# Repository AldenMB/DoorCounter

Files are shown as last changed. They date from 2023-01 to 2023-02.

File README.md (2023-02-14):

# DoorCounter
A IR beam detector for counting when people enter or exit a room, running on a Raspberry Pi Pico.

The DS1302 driver is from [Omar Benhamid](https://github.com/omarbenhamid/micropython-ds1302-rtc). Thanks Omar!

The rotary encoder driver is from [Mike Teachman](https://github.com/miketeachman/micropython-rotary). Thanks Mike!

The circuit board will be held in using 5/16 inch 2-28 pan-head screws. The heads have a diameter of 5/32 inches = 4 mm, The threaded portion has an exterior diameter of 3/32in = 2.3mm, and an inner diameter of about 1/16in = 1.6mm. They measure 3/8 inch in length, counting the head.

## Prototype error
Caution: in my first batch of boards I made an error in the schematic. Of course I take full responsibility, but I feel some blame shoudl also be shared by whoever decided to give one pin of the SD card the designation `DI` and another one the designation `D1`.

The error has already been fixed on the schematic, and it's easy enough to fix. Just break the trace going from `GP3` to the SD card, and instead run a wire to one side of `R3`. Like this:
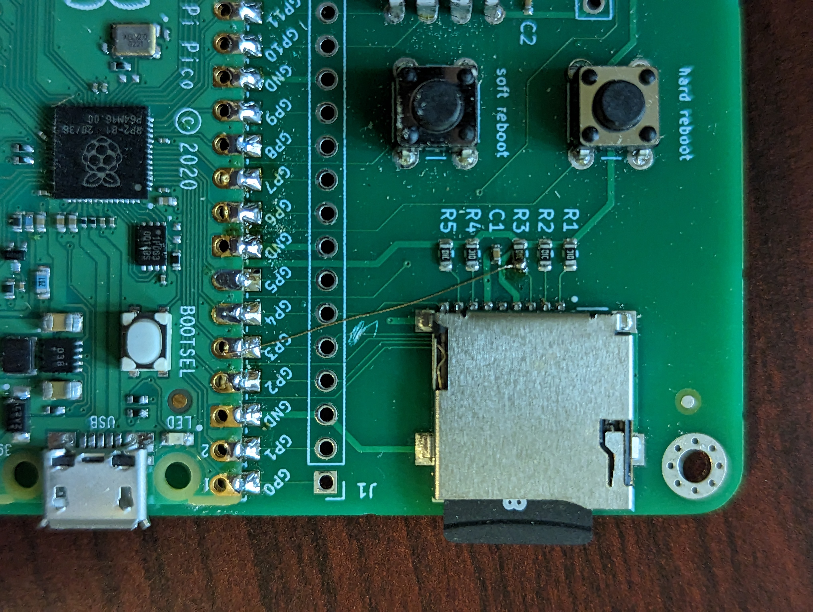
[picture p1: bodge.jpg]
a picture of the board, repaired as described above.

Of course, if you don't use the SD card then this makes no difference. It is still pulled up to the `3V3` line with a 10k resistor.

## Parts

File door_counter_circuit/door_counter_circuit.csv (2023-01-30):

Comment | Designator | Footprint | LCSC
0.1uF | C1,C2,C3,C4,C5,C6,C7 | Capacitor_SMD:C_0402_1005Metric | C1525
TF-01A | MICRO_SD1 | tf01a:TF-01A | C91145
MMS9013-H-TP | Q1 | Package_TO_SOT_SMD:SOT-23 | C90160
10k | R1,R2,R3,R4,R5,R6 | Resistor_SMD:R_0603_1608Metric | C25804
220 | R7 | Resistor_SMD:R_0805_2012Metric | C17557

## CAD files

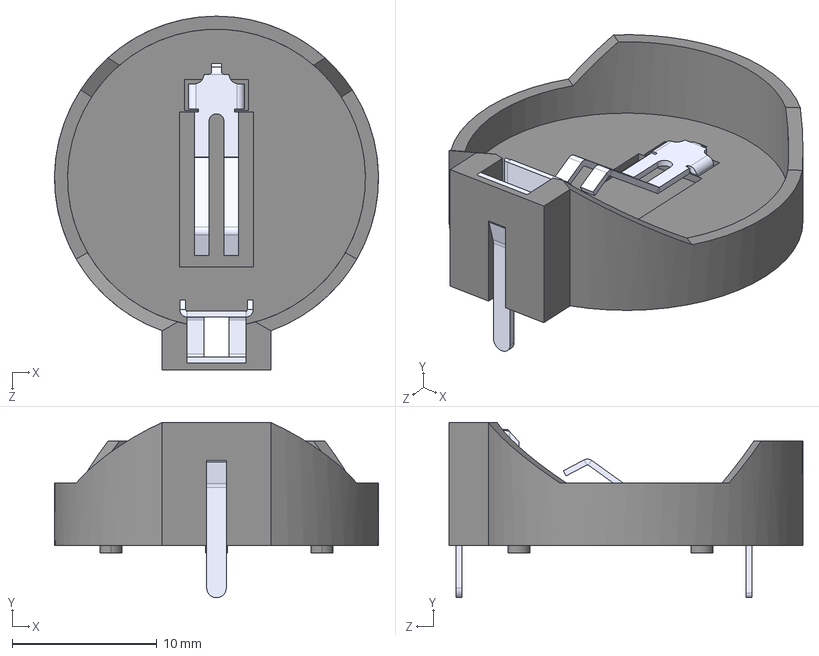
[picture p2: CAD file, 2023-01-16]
door_counter_circuit/BS-7/BS-7.step
22.3 x 12.1 x 24.4 mm

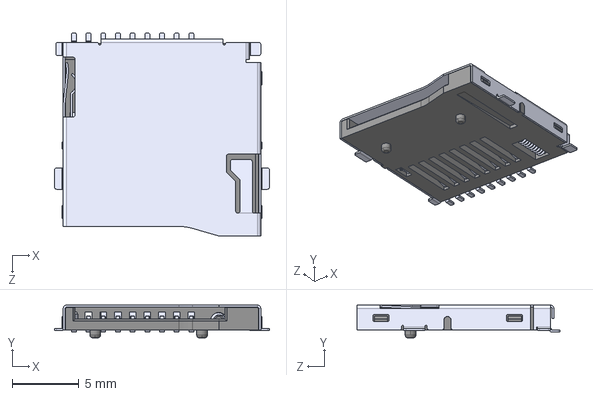
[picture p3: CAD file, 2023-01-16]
door_counter_circuit/TF-01A/TF-01A.step
16.1 x 2.45 x 15.2 mm

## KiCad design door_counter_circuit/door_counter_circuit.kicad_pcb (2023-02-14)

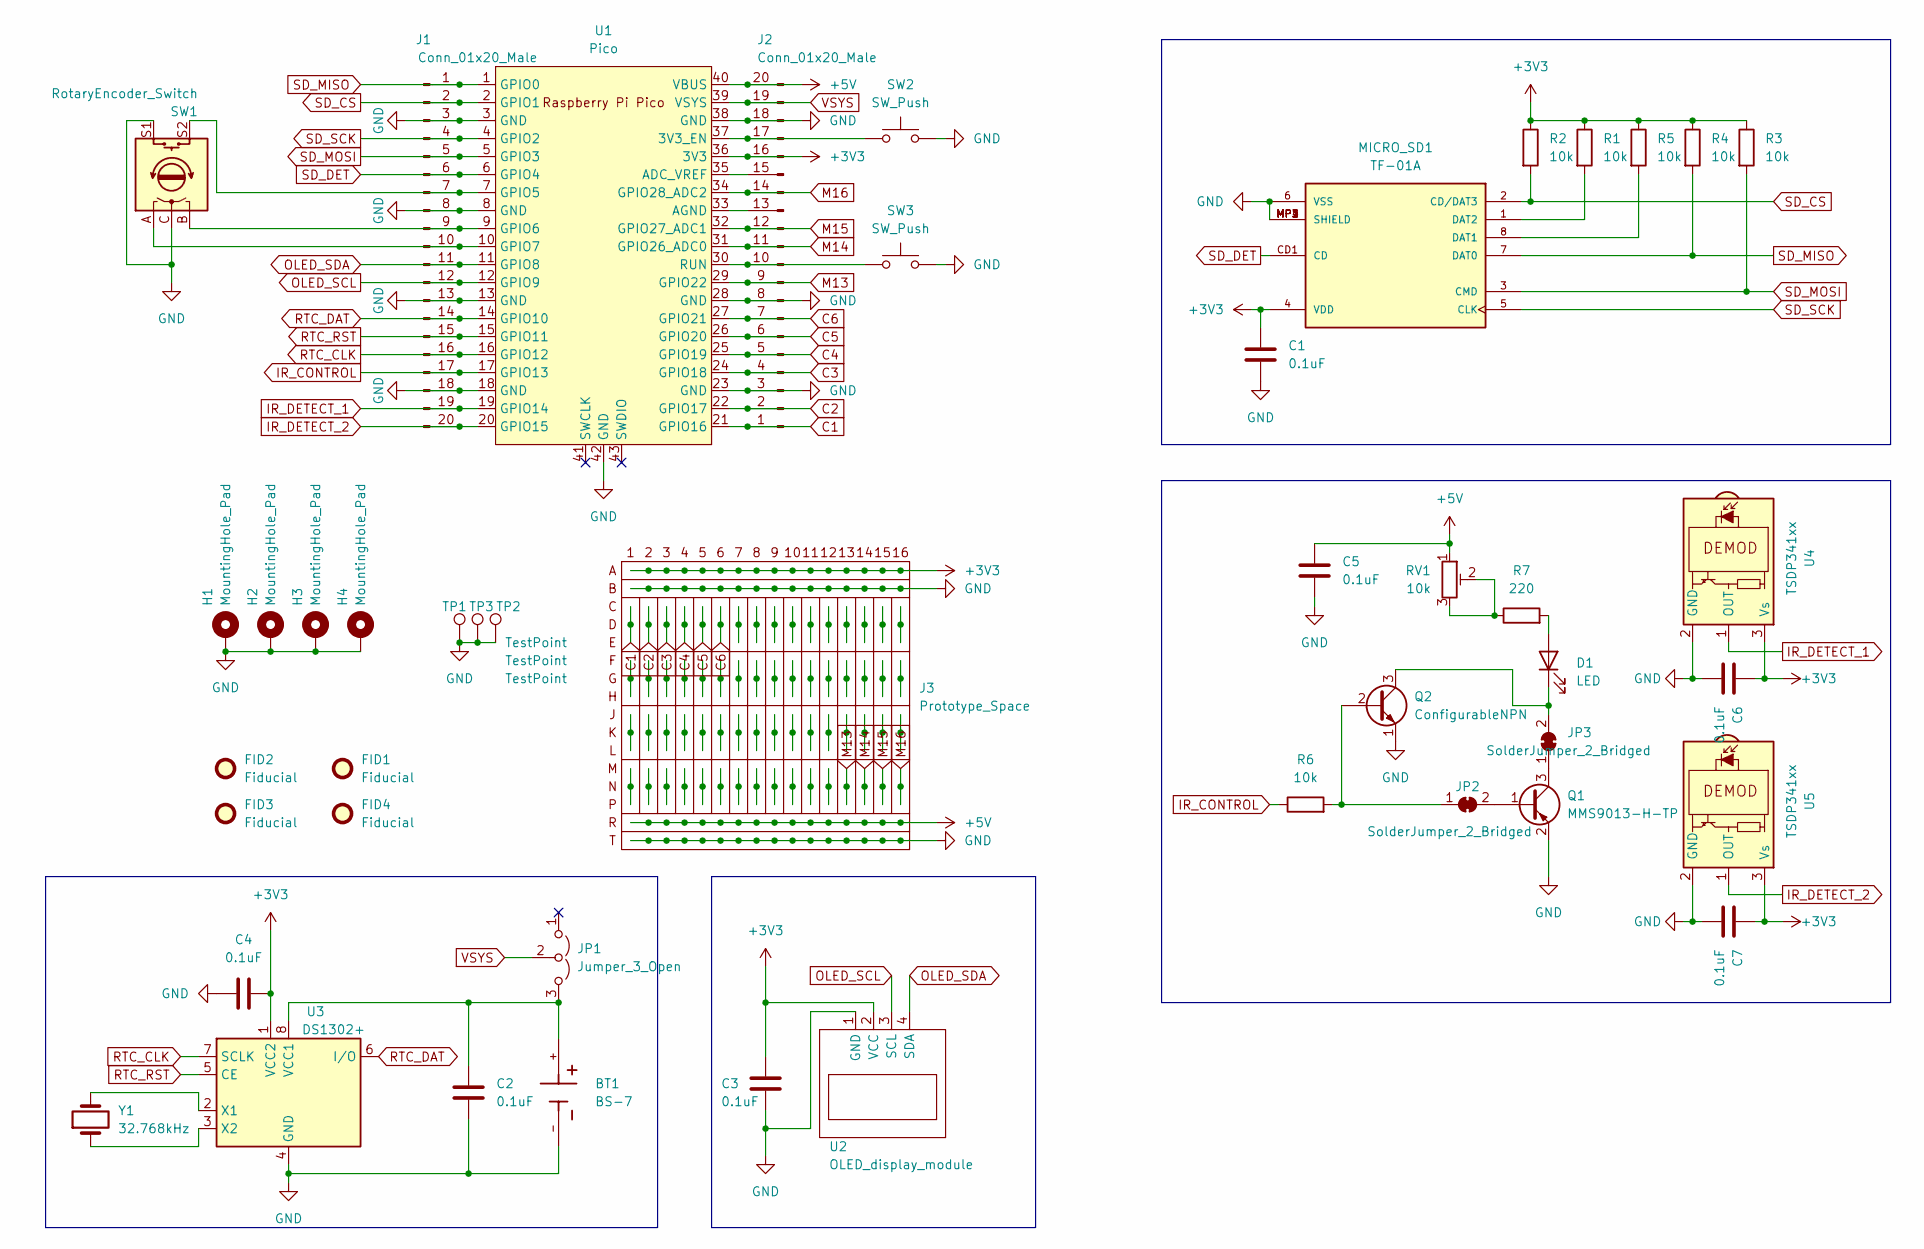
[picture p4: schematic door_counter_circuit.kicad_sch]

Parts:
BT1: BS-7; BAT_BS-7; PARTREV H
C1, C2, C3, C4, C5, C6, C7: 0.1uF; C_0402_1005Metric; LCSC C1525
D1: LED; LED_D3.0mm_Horizontal_O1.27mm_Z6.0mm
FID1, FID2, FID3, FID4: Fiducial; Fiducial_1mm_Mask2mm
H1, H2, H3, H4: MountingHole_Pad; MountingHole_2.5mm_Pad_Via
J1, J2: Conn_01x20_Male; PinHeader_1x20_P2.54mm_Vertical
J3: Prototype_Space; Prototype Space
JP1: Jumper_3_Open; PinHeader_1x03_P2.54mm_Vertical
JP2, JP3: SolderJumper_2_Bridged; SolderJumper-2_P1.3mm_Bridged_RoundedPad1.0x1.5mm
MICRO_SD1: TF-01A; LCSC C91145
Q1: MMS9013-H-TP; SOT-23; LCSC C90160
Q2: ConfigurableNPN; TO-92-configurable
R1, R2, R3, R4, R5, R6: 10k; R_0603_1608Metric; LCSC C25804
R7: 220; R_0805_2012Metric; LCSC C17557
RV1: 10k; Potentiometer_Bourns_3296W_Vertical
SW1: RotaryEncoder_Switch; RotaryEncoder_Alps_EC11E-Switch_Vertical_H20mm
SW2, SW3: SW_Push; SW_PUSH_6mm_H4.3mm
TP1, TP2, TP3: TestPoint; TestPoint_Pad_4.0x4.0mm
U1: Pico; RPi_Pico_SMD_TH
U2: OLED_display_module; SSD1306
U3: DS1302+; DIP-8_W7.62mm
U4, U5: TSDP341xx; Vishay_MOLD-3Pin
Y1: 32.768kHz; Crystal_C26-LF_D2.1mm_L6.5mm_Horizontal

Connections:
+3V3: C1.1, C3.1, C4.2, C6.1, C7.1, J2.16, J3.1A, J3.2A, J3.3A, J3.4A, J3.5A, J3.6A, J3.7A, J3.8A, J3.9A, J3.10A, J3.11A, J3.12A, J3.13A, J3.14A, J3.15A, J3.16A, MICRO_SD1.4 (VDD), R1.1, R2.1, R3.1, R4.1, R5.1, U1.36 (3V3), U2.2 (VCC), U3.1 (VCC2), U4.3 (Vs), U5.3 (Vs)
+5V: C5.1, J2.20, J3.1R, J3.2R, J3.3R, J3.4R, J3.5R, J3.6R, J3.7R, J3.8R, J3.9R, J3.10R, J3.11R, J3.12R, J3.13R, J3.14R, J3.15R, J3.16R, RV1.1, U1.40 (VBUS)
C1: J2.1, J3.1C, J3.1D, J3.1E, U1.21 (GPIO16)
C2: J2.2, J3.2C, J3.2D, J3.2E, U1.22 (GPIO17)
C3: J2.4, J3.3C, J3.3D, J3.3E, U1.24 (GPIO18)
C4: J2.5, J3.4C, J3.4D, J3.4E, U1.25 (GPIO19)
C5: J2.6, J3.5C, J3.5D, J3.5E, U1.26 (GPIO20)
C6: J2.7, J3.6C, J3.6D, J3.6E, U1.27 (GPIO21)
GND: BT1.-, C1.2, C2.2, C3.2, C4.1, C5.2, C6.2, C7.2, H1.1, H2.1, H3.1, H4.1, J1.3, J1.8, J1.13, J1.18, J2.3, J2.8, J2.18, J3.1B, J3.1T, J3.2B, J3.2T, J3.3B, J3.3T, J3.4B, J3.4T, J3.5B, J3.5T, J3.6B, J3.6T, J3.7B, J3.7T, J3.8B, J3.8T, J3.9B, J3.9T, J3.10B, J3.10T, J3.11B, J3.11T, J3.12B, J3.12T, J3.13B, J3.13T, J3.14B, J3.14T, J3.15B, J3.15T, J3.16B, J3.16T, MICRO_SD1.6 (VSS), MICRO_SD1.MP1 (SHIELD), MICRO_SD1.MP2 (SHIELD), MICRO_SD1.MP3 (SHIELD), MICRO_SD1.MP4 (SHIELD), Q1.2 (E), Q2.1 (E), Q2.4 (emitter_duplicate), SW1.C, SW1.S1, SW2.2, SW3.2, TP1.1, TP2.1, TP3.1, U1.3 (GND), U1.8 (GND), U1.13 (GND), U1.18 (GND), U1.23 (GND), U1.28 (GND), U1.38 (GND), U1.42 (GND), U2.1 (GND), U3.4 (GND), U4.2 (GND), U5.2 (GND)
IR_CONTROL: J1.17, R6.1, U1.17 (GPIO13)
IR_DETECT_1: J1.19, U1.19 (GPIO14), U4.1 (OUT)
IR_DETECT_2: J1.20, U1.20 (GPIO15), U5.1 (OUT)
M13: J2.9, J3.13M, J3.13N, J3.13P, U1.29 (GPIO22)
M14: J2.11, J3.14M, J3.14N, J3.14P, U1.31 (GPIO26_ADC0)
M15: J2.12, J3.15M, J3.15N, J3.15P, U1.32 (GPIO27_ADC1)
M16: J2.14, J3.16M, J3.16N, J3.16P, U1.34 (GPIO28_ADC2)
unnamed: BT1.+, C2.1, JP1.3 (B), U3.8 (VCC1)
unnamed: D1.1 (K), JP3.2 (B), Q2.3 (C), Q2.5 (collector_duplicate)
unnamed: D1.2 (A), R7.2
unnamed: J1.7, SW1.S2, U1.7 (GPIO5)
unnamed: J1.9, SW1.B, U1.9 (GPIO6)
unnamed: J1.10, SW1.A, U1.10 (GPIO7)
unnamed: J2.10, SW3.1, U1.30 (RUN)
unnamed: J2.13, U1.33 (AGND)
unnamed: J2.15, U1.35 (ADC_VREF)
unnamed: J2.17, SW2.1, U1.37 (3V3_EN)
unnamed: J3.1F, J3.1G, J3.1H
unnamed: J3.1J, J3.1K, J3.1L
unnamed: J3.1M, J3.1N, J3.1P
unnamed: J3.2F, J3.2G, J3.2H
unnamed: J3.2J, J3.2K, J3.2L
unnamed: J3.2M, J3.2N, J3.2P
unnamed: J3.3F, J3.3G, J3.3H
unnamed: J3.3J, J3.3K, J3.3L
unnamed: J3.3M, J3.3N, J3.3P
unnamed: J3.4F, J3.4G, J3.4H
unnamed: J3.4J, J3.4K, J3.4L
unnamed: J3.4M, J3.4N, J3.4P
unnamed: J3.5F, J3.5G, J3.5H
unnamed: J3.5J, J3.5K, J3.5L
unnamed: J3.5M, J3.5N, J3.5P
unnamed: J3.6F, J3.6G, J3.6H
unnamed: J3.6J, J3.6K, J3.6L
unnamed: J3.6M, J3.6N, J3.6P
unnamed: J3.7C, J3.7D, J3.7E
unnamed: J3.7F, J3.7G, J3.7H
unnamed: J3.7J, J3.7K, J3.7L
unnamed: J3.7M, J3.7N, J3.7P
unnamed: J3.8C, J3.8D, J3.8E
unnamed: J3.8F, J3.8G, J3.8H
unnamed: J3.8J, J3.8K, J3.8L
unnamed: J3.8M, J3.8N, J3.8P
unnamed: J3.9C, J3.9D, J3.9E
unnamed: J3.9F, J3.9G, J3.9H
unnamed: J3.9J, J3.9K, J3.9L
unnamed: J3.9M, J3.9N, J3.9P
unnamed: J3.10C, J3.10D, J3.10E
unnamed: J3.10F, J3.10G, J3.10H
unnamed: J3.10J, J3.10K, J3.10L
unnamed: J3.10M, J3.10N, J3.10P
unnamed: J3.11C, J3.11D, J3.11E
unnamed: J3.11F, J3.11G, J3.11H
unnamed: J3.11J, J3.11K, J3.11L
unnamed: J3.11M, J3.11N, J3.11P
unnamed: J3.12C, J3.12D, J3.12E
unnamed: J3.12F, J3.12G, J3.12H
unnamed: J3.12J, J3.12K, J3.12L
unnamed: J3.12M, J3.12N, J3.12P
unnamed: J3.13C, J3.13D, J3.13E
unnamed: J3.13F, J3.13G, J3.13H
unnamed: J3.13J, J3.13K, J3.13L
unnamed: J3.14C, J3.14D, J3.14E
unnamed: J3.14F, J3.14G, J3.14H
unnamed: J3.14J, J3.14K, J3.14L
unnamed: J3.15C, J3.15D, J3.15E
unnamed: J3.15F, J3.15G, J3.15H
unnamed: J3.15J, J3.15K, J3.15L
unnamed: J3.16C, J3.16D, J3.16E
unnamed: J3.16F, J3.16G, J3.16H
unnamed: J3.16J, J3.16K, J3.16L
unnamed: JP2.1 (A), Q2.2 (B), R6.2
unnamed: JP2.2 (B), Q1.1 (B)
unnamed: JP3.1 (A), Q1.3 (C)
unnamed: MICRO_SD1.1 (DAT2), R1.2
unnamed: MICRO_SD1.8 (DAT1), R5.2
unnamed: R7.1, RV1.2, RV1.3
unnamed: U3.2 (X1), Y1.2
unnamed: U3.3 (X2), Y1.1
OLED_SCL: J1.12, U1.12 (GPIO9), U2.3 (SCL)
OLED_SDA: J1.11, U1.11 (GPIO8), U2.4 (SDA)
RTC_CLK: J1.16, U1.16 (GPIO12), U3.7 (SCLK)
RTC_DAT: J1.14, U1.14 (GPIO10), U3.6 (I/O)
RTC_RST: J1.15, U1.15 (GPIO11), U3.5 (CE)
SD_CS: J1.2, MICRO_SD1.2 (CD/DAT3), R2.2, U1.2 (GPIO1)
SD_DET: J1.6, MICRO_SD1.CD1 (CD), U1.6 (GPIO4)
SD_MISO: J1.1, MICRO_SD1.7 (DAT0), R4.2, U1.1 (GPIO0)
SD_MOSI: J1.5, MICRO_SD1.3 (CMD), R3.2, U1.5 (GPIO3)
SD_SCK: J1.4, MICRO_SD1.5 (CLK), U1.4 (GPIO2)
VSYS: J2.19, JP1.2 (C), U1.39 (VSYS)

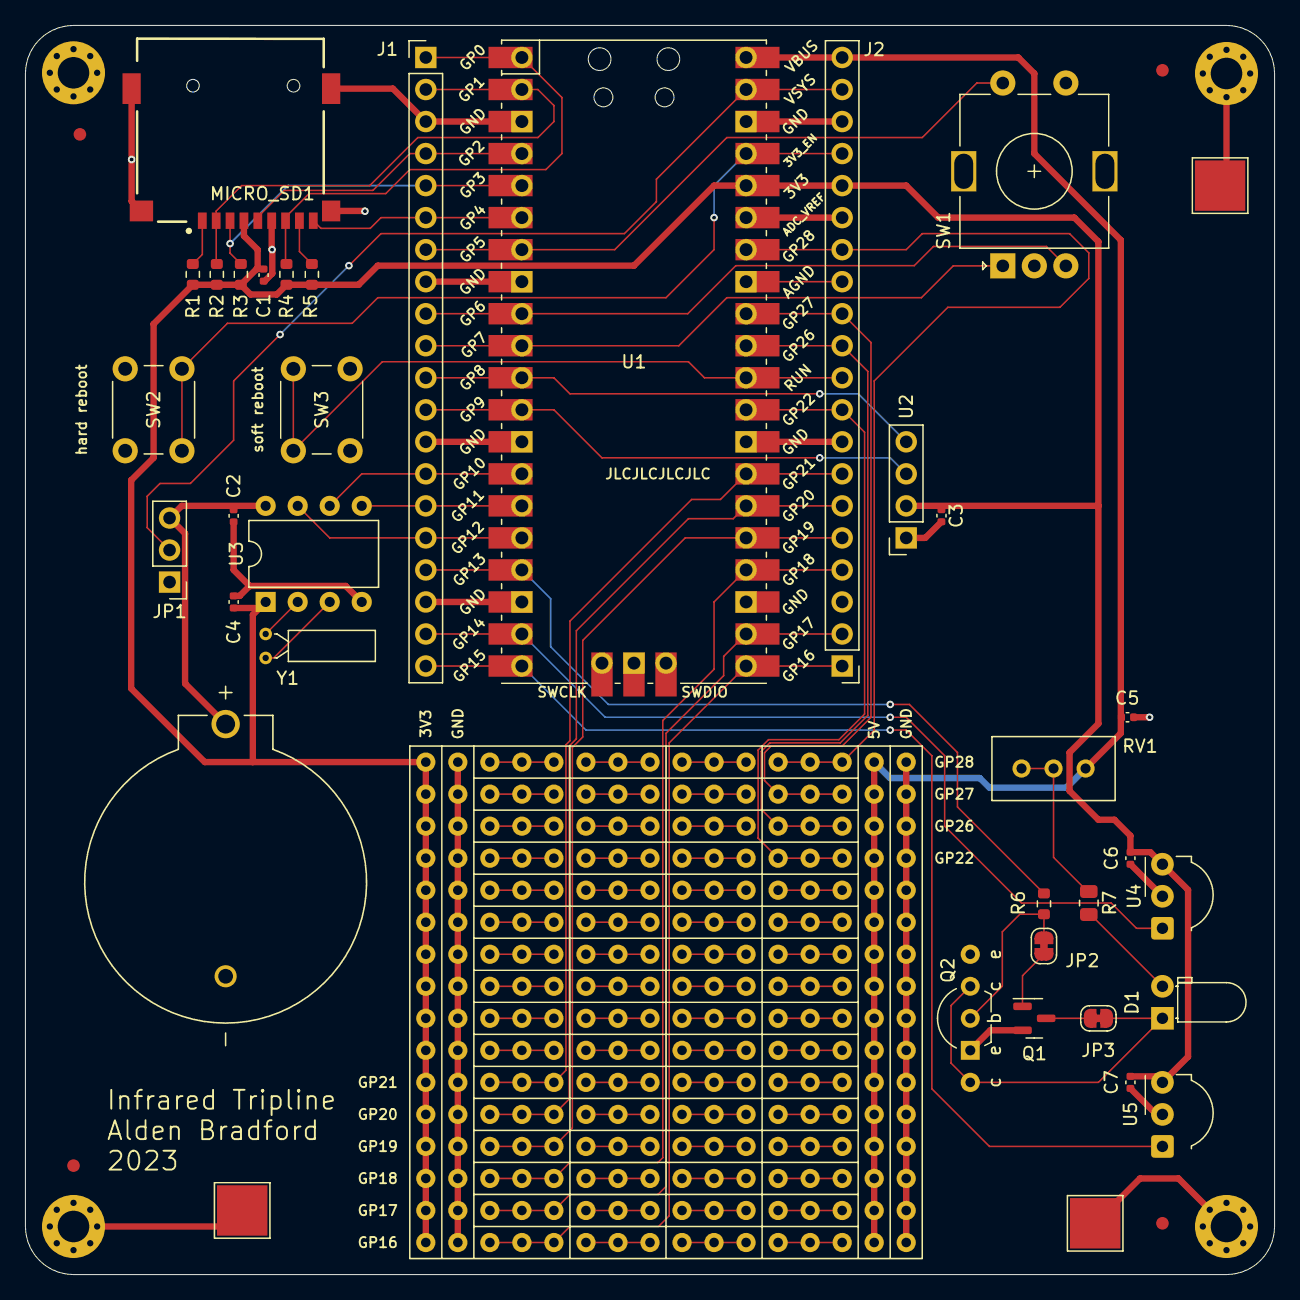
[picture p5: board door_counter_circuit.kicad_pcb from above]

Board: 4 copper layers, 99.1 x 99.1 mm, 46 parts (0 on the bottom side), 99 nets.

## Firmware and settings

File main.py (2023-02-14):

from machine import Pin, I2C, RTC
import time
import rp2
import ssd1306
import rtc_sync
from rotary_irq_rp2 import RotaryIRQ

rtc_sync.load()
clock = RTC()

samples_per_reading = 4
mask = int('0b'+'10'*samples_per_reading)

@rp2.asm_pio(sideset_init=rp2.PIO.OUT_LOW, autopush=True, fifo_join = rp2.PIO.JOIN_RX, push_thresh=samples_per_reading*2)
def ir_echo():
    # datasheet specifies relaxation time >= 5ms
    # total instructions: 3 + 4(2 + 32*8) = 1035
    # 1035 instructions / 76k instr/sec = 13.6 ms
    set(y, 4)  # 1
    label("blank")
    set(x, 31)  # 4 * 1
    label("blank_inner")
    jmp(x_dec, "blank_inner").delay(7)  # 4*32*8
    jmp(y_dec, "blank")  # 4 * 1

    # datasheet specifies at least 10 pulses per burst
    # NEC protocol uses 21 pulse and 237 pulse bursts
    set(x, 20)  # 1
    label("burst")
    nop().side(1)
    jmp(x_dec, "burst").side(0)
    # 32 pulses / 38khz = 842 us
    
    # response may terminate as early as 6 instructions after last pulse
    # we should take the measurement immediately
    in_(pins, 2) # 1

# asm_pio does not have an input pullup flag, for some reason. Oh well. Set them manually.
Pin(14, Pin.IN, Pin.PULL_UP)
Pin(15, Pin.IN, Pin.PULL_UP)
sensor = rp2.StateMachine(0, ir_echo, freq=2 * 38_000, sideset_base=Pin(13), in_base = Pin(14))
sensor.active(True)

i2c = I2C(id=0, sda=Pin(8), scl=Pin(9))
display = ssd1306.SSD1306_I2C(128, 64, i2c)
display.text('Hello, World!', 0, 0, 1)
display.show()

onboard_led = Pin(25, Pin.OUT)

rotary = RotaryIRQ(6, 7, pull_up=True)
button = Pin(3, Pin.IN, Pin.PULL_UP)

while True:
    display.fill(0)
        
    word = sensor.get()
    A = samples_per_reading- (bin(word & (mask>>1)).count('1'))
    B = samples_per_reading- (bin(word & mask).count('1'))
    
    display.text(f'{A:2d}', 0, 0, 1)
    display.rect(0, 10, 128*A//samples_per_reading, 4, 1)
    display.text(f'{B:2d}', 0, 20, 1)
    display.rect(0, 30, 128*B//samples_per_reading, 4, 1)
    
    display.text(f'{rotary.value()}', 0, 40, 1)
    
    year, month, day, weekday, hour, minute, second, *_ = clock.datetime()
    display.text(f'{year:4d}/{month:02d}/{day:02d}', 0, 48, 1)
    display.text(f'{hour:02d}:{minute:02d}:{second:02d}', 0, 56, 1)
    display.show()
    
    onboard_led.value(not button.value())

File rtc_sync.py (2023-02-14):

from machine import Pin, RTC
import ds1302

external = ds1302.DS1302(clk = Pin(12), dio = Pin(10), cs = Pin(11))
internal = RTC()

def show():
    print(f'''\
external clock: {external.date_time()}
internal clock: {internal.datetime()}''')
    
def save():
    print('Synchronizing clocks...', end = '')
    external.date_time(internal.datetime())
    print(' ...done!')

def load():
    internal.datetime(external.date_time()+[0])

if __name__ == '__main__':
    show()
    save()
    show()

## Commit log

2023-01-13 read from sensors in PIO loop
2023-01-15 begin circuit schematic
    [door_counter_circuit.kicad_pcb, door_counter_circuit.kicad_sch]
2023-01-15 RTC driver
2023-01-16 circuit board drafted
    [BS-7.step, TF-01A.step, door_counter_circuit.kicad_pcb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]
2023-01-30 include measurements for screws
2023-01-30 include a configurable transistor footprint
    [door_counter_circuit.kicad_pcb, door_counter_circuit.kicad_sch]
2023-01-30 manufacturing outputs
    [door_counter_circuit-B_Mask.gbs, door_counter_circuit-B_Paste.gbp, door_counter_circuit-B_Silkscreen.gbo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]
2023-02-14 match pinout of PCB
2023-02-14 fix to SD circuit
    [door_counter_circuit-B_Mask.gbs, door_counter_circuit-B_Paste.gbp, door_counter_circuit-B_Silkscreen.gbo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]
